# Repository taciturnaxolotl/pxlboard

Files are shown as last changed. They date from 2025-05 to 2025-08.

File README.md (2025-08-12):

# PxlBoard

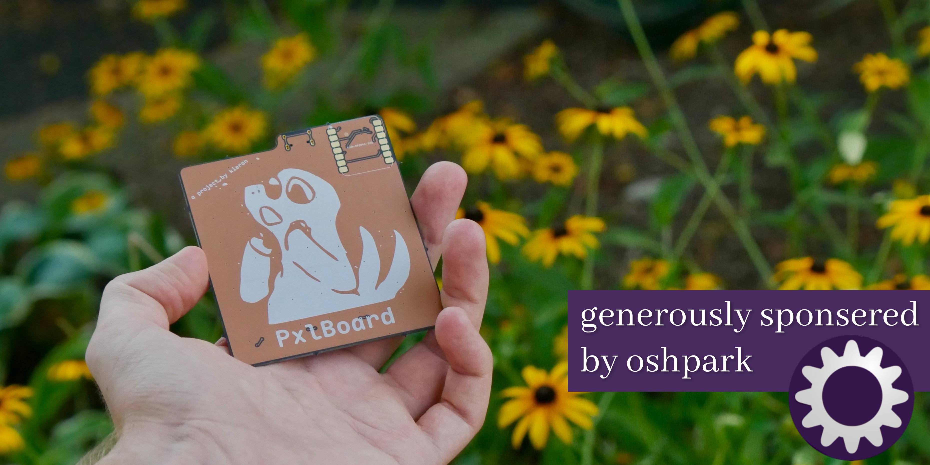
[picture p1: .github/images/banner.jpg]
the back of the pcb held in my hand over some black eyed susans


## BOM

| Part | Quantity | Price  | LCSC | Notes |
| --- | --- | --- | --- | --- |
| PCB (OSHPark) | 1 | $47.25 | | Purple PCB; Most expensive manufacturer but also looks gorgeous |
| PCB (JLCPCB) | 1 | $24.82 | | Custom PCB - Green; Mid-range price |
| PCB (PCBWay) | 1 | $12.80 | | Custom PCB - Various colors; Most affordable option (kinda suprisingly?) |
| Seeed XIAO RP2040 | 1 | $3.99  | [Seeed Studio](https://www.seeedstudio.com/XIAO-RP2040-v1-0-p-5026.html) | Brain of the operation |
| SK6812 LEDs | 65 | $6.40  | [C5380879](https://www.lcsc.com/product-detail/RGB-LEDs-Built-in-IC_OPSCO-Optoelectronics-SKC6812RGBW-WS-B_C5380879.html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) | RGB addressable LEDs; $0.0985 each, forms the 8x8 grid |
| LIS3DHTR Accelerometer | 1 | $0.60  | [C15134](https://www.lcsc.com/product-detail/Accelerometers_STMicroelectronics-LIS3DHTR_C15134.html?s_z=n_LIS3DHTR) | 3-axis accelerometer; same as the one used on the spark tilt jam |
| Capacitor 100nF - ceramic | 20 (min size) need 1 | $0.29  | [C24497](https://www.lcsc.com/product-detail/Multilayer-Ceramic-Capacitors-MLCC-SMD-SMT_Samsung-Electro-Mechanics-CL31B104KBCNNNC_C24497.html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) | 1206 package |
| Capacitor 10uF - ceramic | 10 (min size) need 9 | $0.34  | [C13585](https://www.lcsc.com/product-detail/Multilayer-Ceramic-Capacitors-MLCC-SMD-SMT_Samsung-Electro-Mechanics-CL31A106KBHNNNE_C13585.html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) | 1206 package |
| Capacitor 10nf - ceramic | 20 (min size) need 1 | $0.23  | [C1846](https://www.lcsc.com/product-detail/Multilayer-Ceramic-Capacitors-MLCC-SMD-SMT_FH-Guangdong-Fenghua-Advanced-Tech-1206B103K500NT_C1846.html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) | 1206 package |
| Capacitor 100uF - electrolytic | 5 (min size) need 1  | $0.87  | [C1954161](https://www.lcsc.com/product-detail/Tantalum-Capacitors_Vishay-Intertech-TMCMA0J107MTRF_C1954161.html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) | 1206 package |
| Capacitor 470uF - polymer | 5 (min size) need 1  | $0.59  | [C41410213](https://www.lcsc.com/product-detail/Polymer-Aluminum-Capacitors_Yunxing-SPT1AM471E09TRVZC_C41410213.html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) | 10V 470uF Polymer ±20% SMD,D6.3xL9mm Polymer Aluminum Capacitors ROHS |
| USB-c connector | 5 (min size) need 1  | $0.87  | [C165948](https://www.lcsc.com/product-detail/C165948.html) | 5A 1 16P Female Type-C SMD USB Connectors ROHS |

Total (with pcbway): ~$28.25

## Schematics

> If you want an iteractive version use [`kicanvas`](https://kicanvas.org/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)!

schematic

<div align="center">
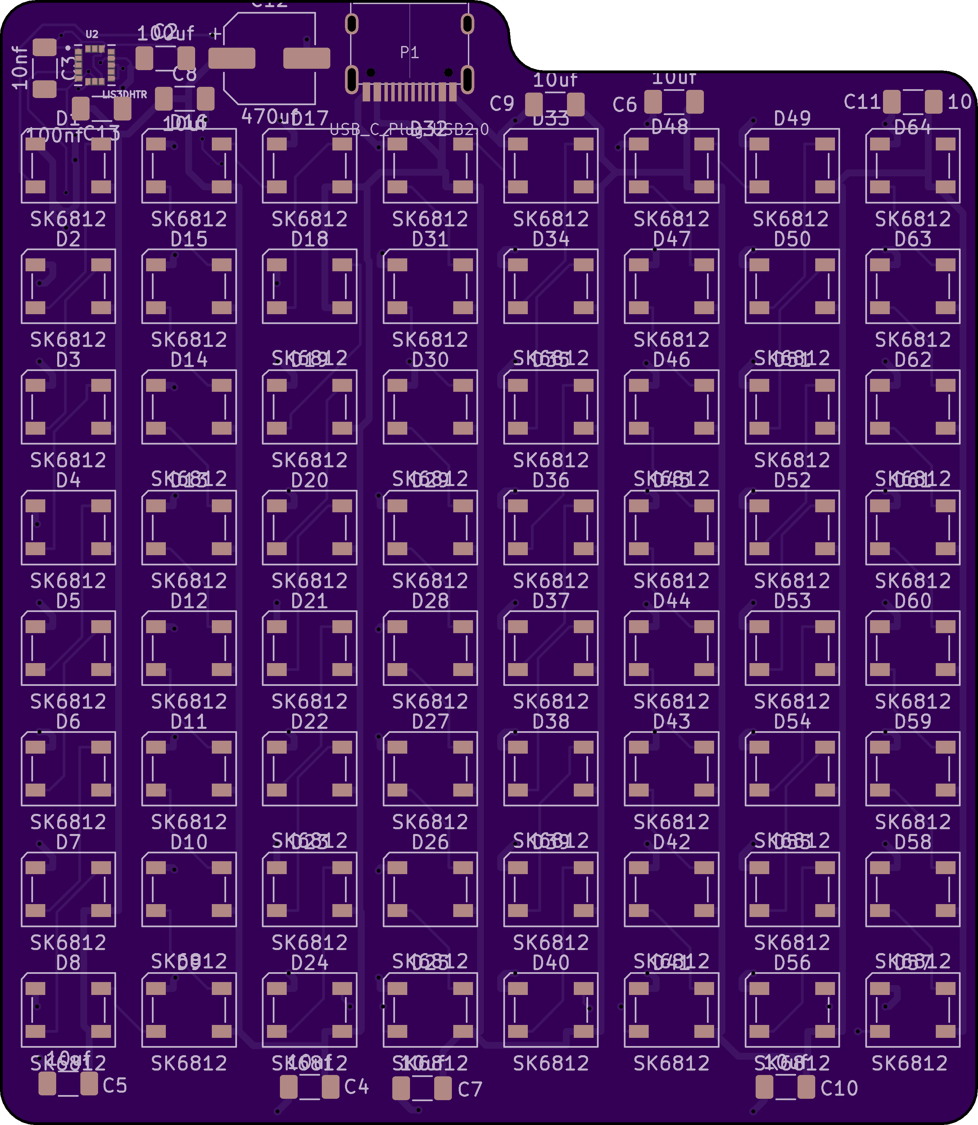
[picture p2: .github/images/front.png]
  
  
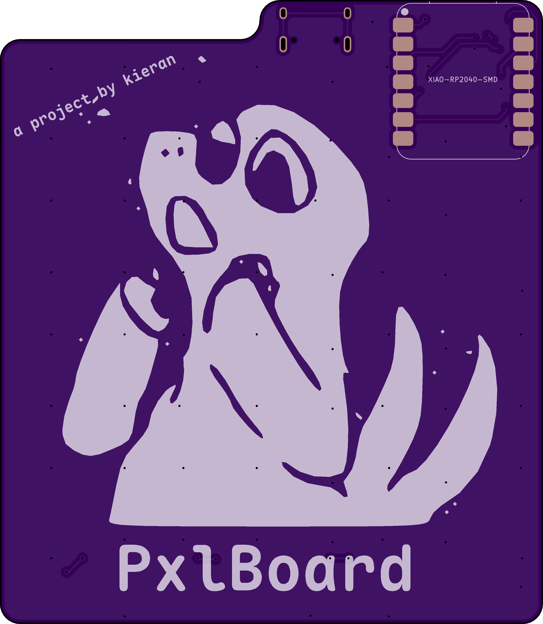
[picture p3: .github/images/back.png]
  
</div>

### Pinout

#### XIAO RP2040 Connections

| XIAO Pin | Connected To | Description |
| --- | --- | --- |
| D0/GPIO26/A0 | - | Unused |
| D1/GPIO27/A1 | - | Unused |
| D2/GPIO28/A2 | - | Unused |
| D3/GPIO29/A3 | - | Unused |
| D4/GPIO6/SDA | LIS3DHTR SDA | I2C Data Line  |
| D5/GPIO7/SCL | LIS3DHTR SCL | I2C Clock Line |
| D6/GPIO0/TX | - | Unused |
| D7/GPIO1/RX | NEOPIXEL_SIG | LED Data In |
| D8/GPIO2/SCK | - | Unused |
| D9/GPIO4/MISO  | - | Unused |
| D10/GPIO3/MOSI | - | Unused |
| 3V3 | LIS3DHTR VDD_IO | 3.3V Power |
| GND | LIS3DHTR GND, LEDs GND | Ground |
| 5V | LEDs VDD | 5V Power |

#### LIS3DHTR Accelerometer

| LIS3DHTR Pin | Connected To | Description |
| --- | --- | --- |
| VDD | 3.3V | Power Supply |
| VDD_IO | 3.3V | Interface Power |
| GND | GND | Ground |
| SDA | XIAO D4 | I2C Data |
| SCL | XIAO D5 | I2C Clock |
| INT1 | - | Interrupt (not used) |
| INT2 | - | Interrupt (not used) |

<p align="center">
	
</p>

<p align="center">
	<i><code>&copy 2025-present <a href="https://github.com/taciturnaxolotl">Kieran Klukas</a></code></i>
</p>

<p align="center">
	
</p>

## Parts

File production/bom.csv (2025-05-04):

Comment | Designator | Footprint | LCSC | Quantity
XIAO-RP2040-SMD | U1 | XIAO-RP2040-SMD | N/A | 1
SK6812 | D39,D31,D18,D37,D28,D21,D5,D3,D44,D24,D63,D52,D42,D56,D4,D43,D49,D60,D53,D62,D40,D50,D20,D41,D8,D30,D10,D58,D57,D33,D25,D16,D17,D23,D46,D59,D64,D27,D61,D7,D12,D19,D14,D36,D48,D54,D45,D55,D2,D29,D34,D35,D47,D1,D6,D26,D15,D38,D51,D9,D13,D22,D11,D32 | LED_SK6812_PLCC4_5.0x5.0mm_P3.2mm | C5380879 | 64
LIS3DHTR | U2 | XDCR_LIS3DHTR | C15134 | 1
100nF | C13 | C_1206_3216Metric_Pad1.33x1.80mm_HandSolder | C24497 | 1
10uF | C11,C4,C5,C10,C9,C8,C7,C6 | C_1206_3216Metric_Pad1.33x1.80mm_HandSolder | C13585 | 8
470uF | C12 | CP_Elec_6.3x9.9 | C41410213 | 1
100uF | C2 | C_1206_3216Metric_Pad1.33x1.80mm_HandSolder | C1954161 | 1
10nF | C3 | C_1206_3216Metric_Pad1.33x1.80mm_HandSolder | C1846 | 1

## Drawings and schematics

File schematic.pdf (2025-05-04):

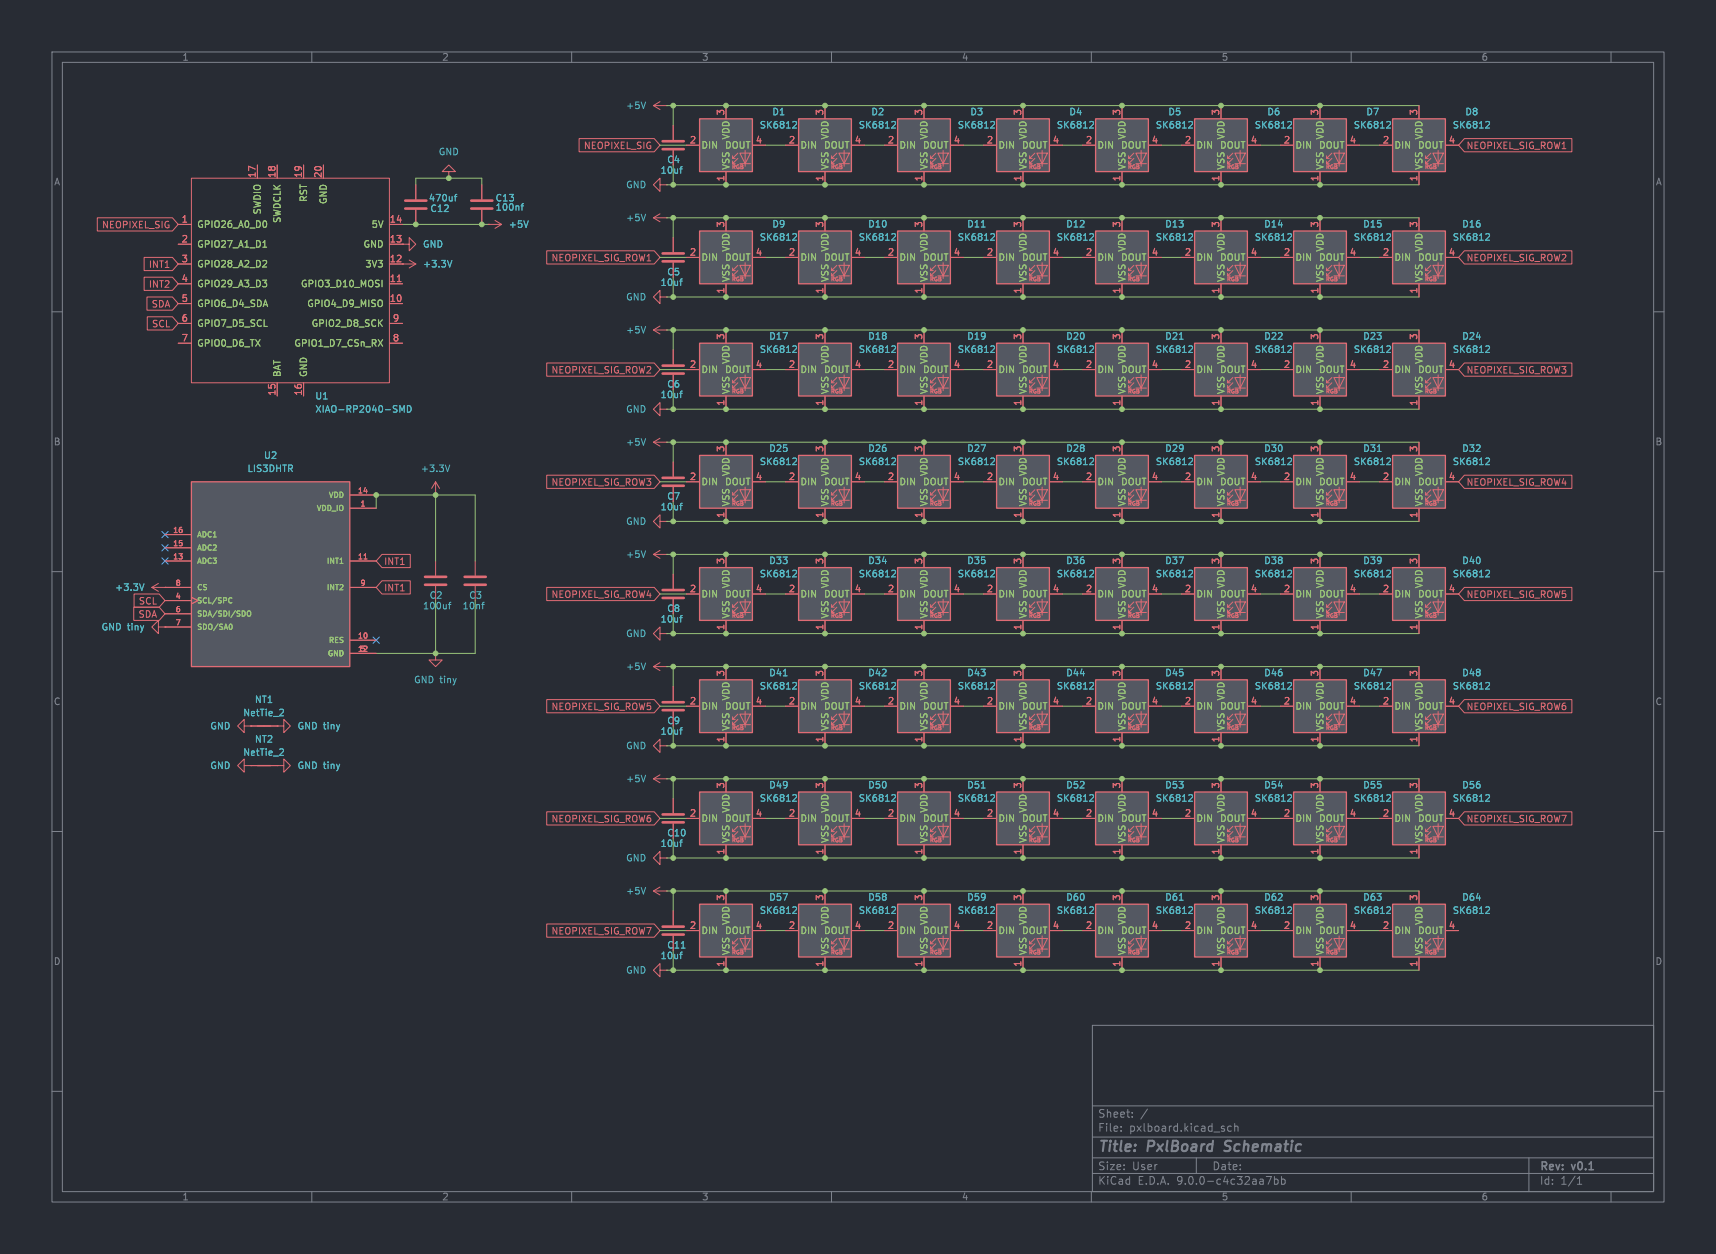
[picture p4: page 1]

1 DOUT 4 D32 SK6812 +3.3V GPIO26_A0_D0 1 GPIO27_A1_D1 2 GPIO28_A2_D2 3 GPIO29_A3_D3 4 GPIO6_D4_SDA 5 GPIO7_D5_SCL 6 GPIO0_D6_TX 7 SWDIO 17 SWDCLK 18 BAT 15 RST 19 GND 16 GND 20

1 DOUT 4 D39 SK6812 NT1 NetTie_2 GND GND tiny NT2 NetTie_2

File: pxlboard.kicad_sch Sheet: /
Id: 1/1 Title: PxlBoard Schematic

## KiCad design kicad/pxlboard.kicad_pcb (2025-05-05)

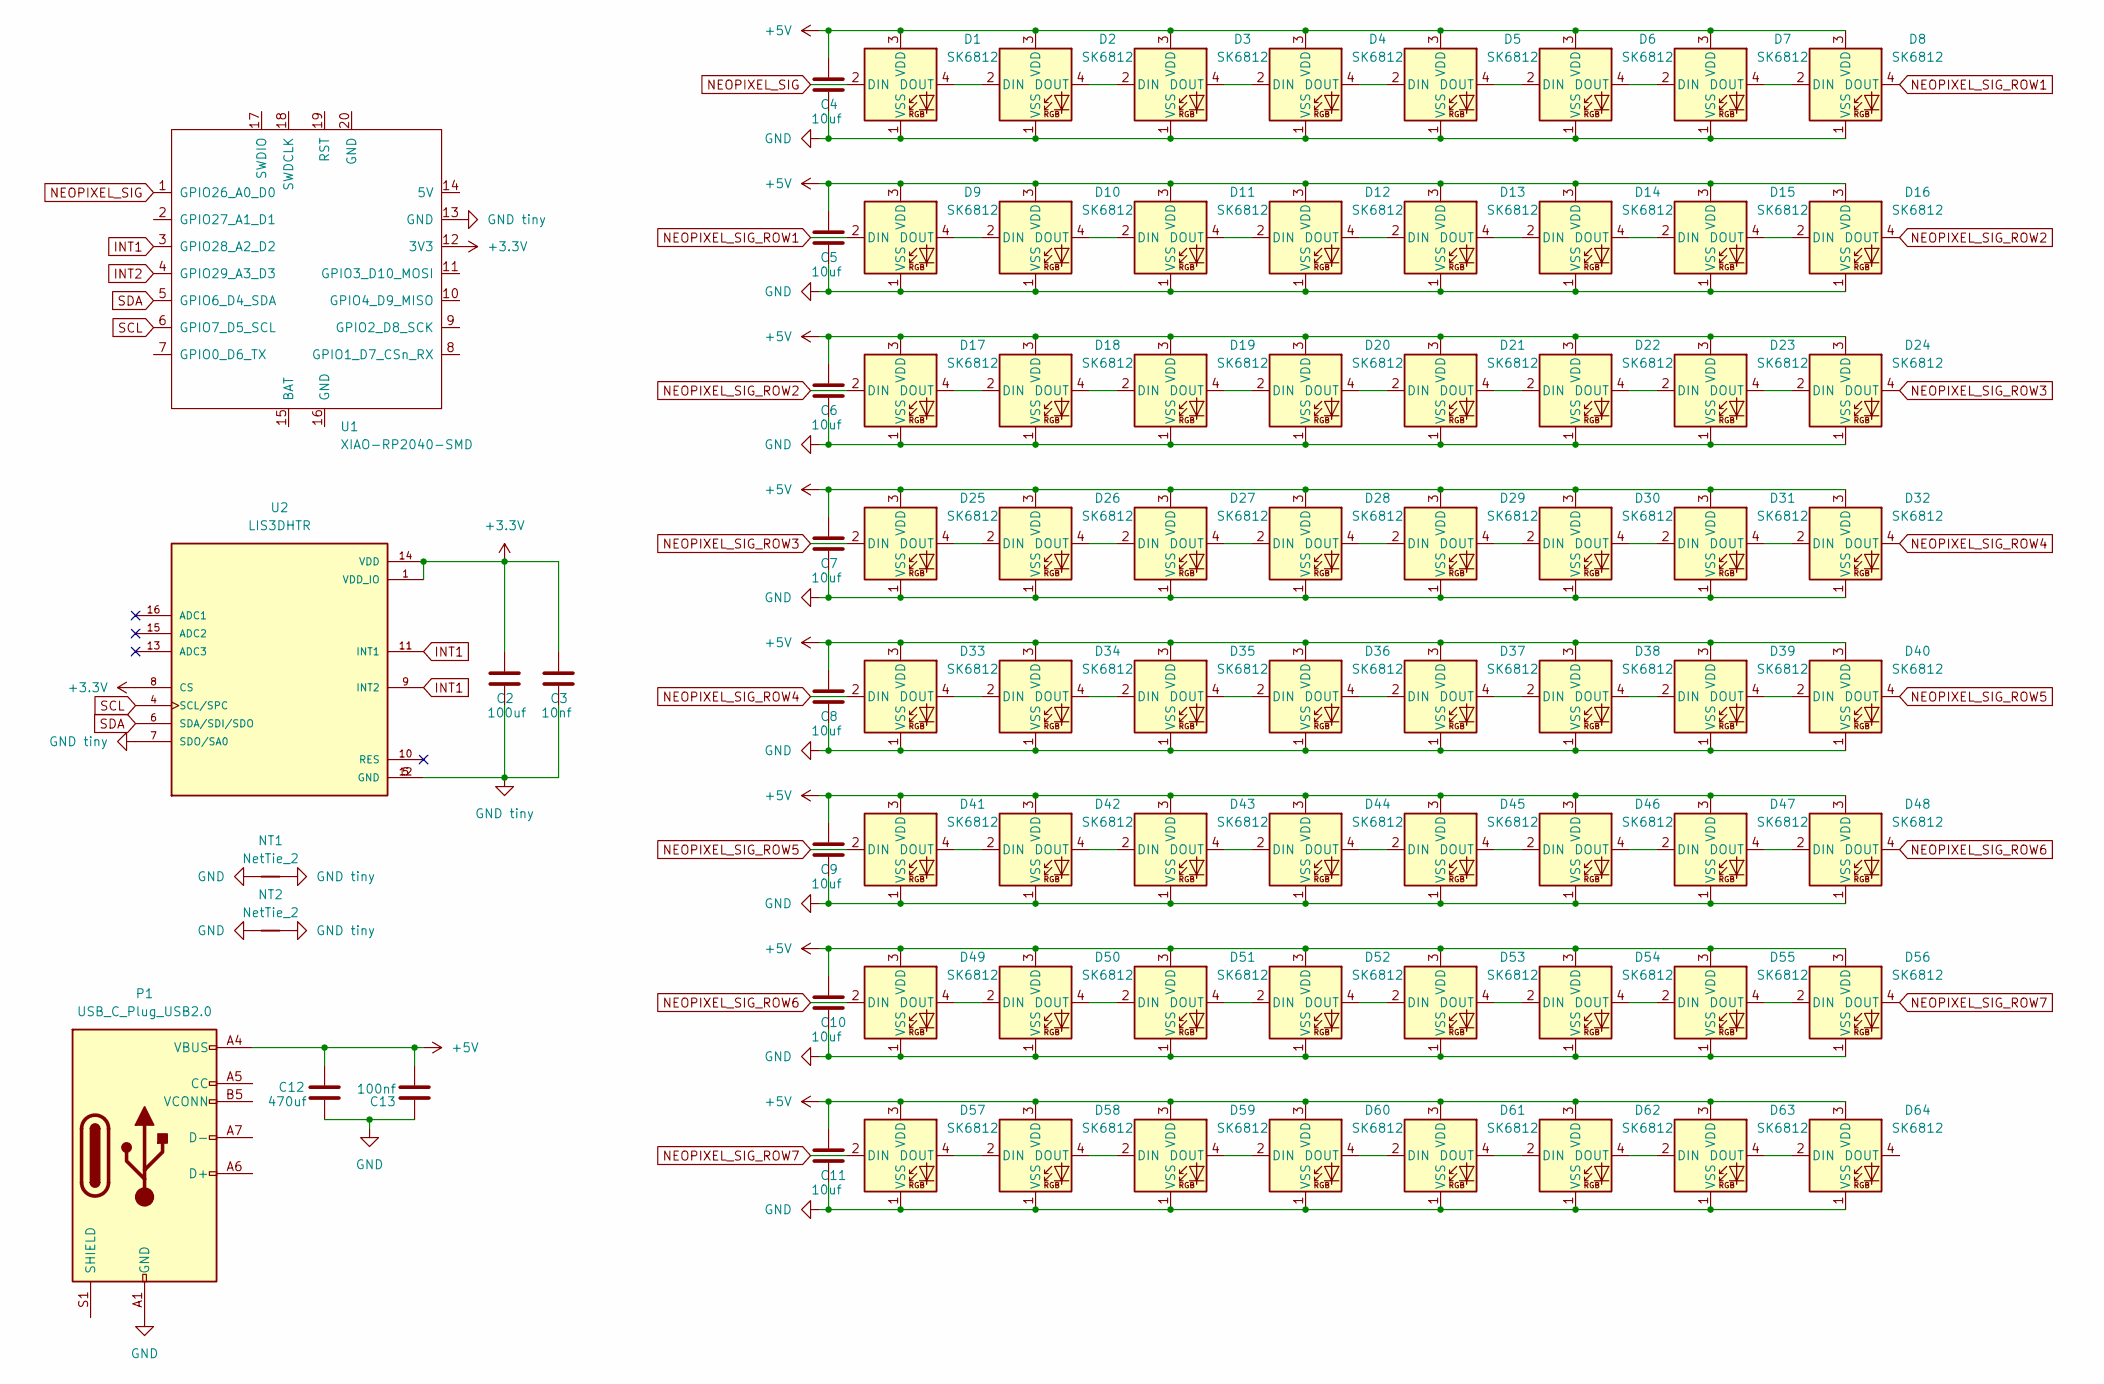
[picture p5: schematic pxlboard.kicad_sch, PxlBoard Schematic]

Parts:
C2: 100uf; C_1206_3216Metric_Pad1.33x1.80mm_HandSolder
C3: 10nf; C_1206_3216Metric_Pad1.33x1.80mm_HandSolder
C4, C5, C6, C7, C8, C9, C10, C11: 10uf; C_1206_3216Metric_Pad1.33x1.80mm_HandSolder
C12: 470uf; CP_Elec_6.3x9.9
C13: 100nf; C_1206_3216Metric_Pad1.33x1.80mm_HandSolder
D1, D2, D3, D4, D5, D6, D7, D8, D9, D10, D11, D12, D13, D14, D15, D16, D17, D18, D19, D20, D21, D22, D23, D24, D25, D26, D27, D28, D29, D30, D31, D32, D33, D34, D35, D36, D37, D38, D39, D40, D41, D42, D43, D44, D45, D46, D47, D48, D49, D50, D51, D52, D53, D54, D55, D56, D57, D58, D59, D60, D61, D62, D63, D64: SK6812; LED_SK6812_PLCC4_5.0x5.0mm_P3.2mm
NT1, NT2: NetTie_2; NetTie-2_SMD_Pad0.5mm
P1: USB_C_Plug_USB2.0; TYPE-C-31-M-12
U1: XIAO-RP2040-SMD
U2: LIS3DHTR; XDCR_LIS3DHTR; PARTREV 2; DigiKey_Part_Number 497-10613-2-ND

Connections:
+3.3V: C2.1, C3.1, U1.12 (3V3), U2.1 (VDD_IO), U2.8 (CS), U2.14 (VDD)
+5V: C4.1, C5.1, C6.1, C7.1, C8.1, C9.1, C10.1, C11.1, C12.1, C13.2, D1.3 (VDD), D2.3 (VDD), D3.3 (VDD), D4.3 (VDD), D5.3 (VDD), D6.3 (VDD), D7.3 (VDD), D8.3 (VDD), D9.3 (VDD), D10.3 (VDD), D11.3 (VDD), D12.3 (VDD), D13.3 (VDD), D14.3 (VDD), D15.3 (VDD), D16.3 (VDD), D17.3 (VDD), D18.3 (VDD), D19.3 (VDD), D20.3 (VDD), D21.3 (VDD), D22.3 (VDD), D23.3 (VDD), D24.3 (VDD), D25.3 (VDD), D26.3 (VDD), D27.3 (VDD), D28.3 (VDD), D29.3 (VDD), D30.3 (VDD), D31.3 (VDD), D32.3 (VDD), D33.3 (VDD), D34.3 (VDD), D35.3 (VDD), D36.3 (VDD), D37.3 (VDD), D38.3 (VDD), D39.3 (VDD), D40.3 (VDD), D41.3 (VDD), D42.3 (VDD), D43.3 (VDD), D44.3 (VDD), D45.3 (VDD), D46.3 (VDD), D47.3 (VDD), D48.3 (VDD), D49.3 (VDD), D50.3 (VDD), D51.3 (VDD), D52.3 (VDD), D53.3 (VDD), D54.3 (VDD), D55.3 (VDD), D56.3 (VDD), D57.3 (VDD), D58.3 (VDD), D59.3 (VDD), D60.3 (VDD), D61.3 (VDD), D62.3 (VDD), D63.3 (VDD), D64.3 (VDD), P1.A4 (VBUS), P1.A9 (VBUS), P1.B4 (VBUS), P1.B9 (VBUS)
GND: C4.2, C5.2, C6.2, C7.2, C8.2, C9.2, C10.2, C11.2, C12.2, C13.1, D1.1 (VSS), D2.1 (VSS), D3.1 (VSS), D4.1 (VSS), D5.1 (VSS), D6.1 (VSS), D7.1 (VSS), D8.1 (VSS), D9.1 (VSS), D10.1 (VSS), D11.1 (VSS), D12.1 (VSS), D13.1 (VSS), D14.1 (VSS), D15.1 (VSS), D16.1 (VSS), D17.1 (VSS), D18.1 (VSS), D19.1 (VSS), D20.1 (VSS), D21.1 (VSS), D22.1 (VSS), D23.1 (VSS), D24.1 (VSS), D25.1 (VSS), D26.1 (VSS), D27.1 (VSS), D28.1 (VSS), D29.1 (VSS), D30.1 (VSS), D31.1 (VSS), D32.1 (VSS), D33.1 (VSS), D34.1 (VSS), D35.1 (VSS), D36.1 (VSS), D37.1 (VSS), D38.1 (VSS), D39.1 (VSS), D40.1 (VSS), D41.1 (VSS), D42.1 (VSS), D43.1 (VSS), D44.1 (VSS), D45.1 (VSS), D46.1 (VSS), D47.1 (VSS), D48.1 (VSS), D49.1 (VSS), D50.1 (VSS), D51.1 (VSS), D52.1 (VSS), D53.1 (VSS), D54.1 (VSS), D55.1 (VSS), D56.1 (VSS), D57.1 (VSS), D58.1 (VSS), D59.1 (VSS), D60.1 (VSS), D61.1 (VSS), D62.1 (VSS), D63.1 (VSS), D64.1 (VSS), NT1.1, NT2.1, P1.A1 (GND), P1.A12 (GND), P1.B1 (GND), P1.B12 (GND)
GND tiny: C2.2, C3.2, NT1.2, NT2.2, U1.13 (GND), U2.5 (GND), U2.7 (SDO/SA0), U2.12 (GND)
INT1: U1.3 (GPIO28_A2_D2), U2.9 (INT2), U2.11 (INT1)
INT2: U1.4 (GPIO29_A3_D3)
NEOPIXEL_SIG: D1.2 (DIN), U1.1 (GPIO26_A0_D0)
NEOPIXEL_SIG_ROW1: D8.4 (DOUT), D9.2 (DIN)
NEOPIXEL_SIG_ROW2: D16.4 (DOUT), D17.2 (DIN)
NEOPIXEL_SIG_ROW3: D24.4 (DOUT), D25.2 (DIN)
NEOPIXEL_SIG_ROW4: D32.4 (DOUT), D33.2 (DIN)
NEOPIXEL_SIG_ROW5: D40.4 (DOUT), D41.2 (DIN)
NEOPIXEL_SIG_ROW6: D48.4 (DOUT), D49.2 (DIN)
NEOPIXEL_SIG_ROW7: D56.4 (DOUT), D57.2 (DIN)
unnamed: D1.4 (DOUT), D2.2 (DIN)
unnamed: D2.4 (DOUT), D3.2 (DIN)
unnamed: D3.4 (DOUT), D4.2 (DIN)
unnamed: D4.4 (DOUT), D5.2 (DIN)
unnamed: D5.4 (DOUT), D6.2 (DIN)
unnamed: D6.4 (DOUT), D7.2 (DIN)
unnamed: D7.4 (DOUT), D8.2 (DIN)
unnamed: D9.4 (DOUT), D10.2 (DIN)
unnamed: D10.4 (DOUT), D11.2 (DIN)
unnamed: D11.4 (DOUT), D12.2 (DIN)
unnamed: D12.4 (DOUT), D13.2 (DIN)
unnamed: D13.4 (DOUT), D14.2 (DIN)
unnamed: D14.4 (DOUT), D15.2 (DIN)
unnamed: D15.4 (DOUT), D16.2 (DIN)
unnamed: D17.4 (DOUT), D18.2 (DIN)
unnamed: D18.4 (DOUT), D19.2 (DIN)
unnamed: D19.4 (DOUT), D20.2 (DIN)
unnamed: D20.4 (DOUT), D21.2 (DIN)
unnamed: D21.4 (DOUT), D22.2 (DIN)
unnamed: D22.4 (DOUT), D23.2 (DIN)
unnamed: D23.4 (DOUT), D24.2 (DIN)
unnamed: D25.4 (DOUT), D26.2 (DIN)
unnamed: D26.4 (DOUT), D27.2 (DIN)
unnamed: D27.4 (DOUT), D28.2 (DIN)
unnamed: D28.4 (DOUT), D29.2 (DIN)
unnamed: D29.4 (DOUT), D30.2 (DIN)
unnamed: D30.4 (DOUT), D31.2 (DIN)
unnamed: D31.4 (DOUT), D32.2 (DIN)
unnamed: D33.4 (DOUT), D34.2 (DIN)
unnamed: D34.4 (DOUT), D35.2 (DIN)
unnamed: D35.4 (DOUT), D36.2 (DIN)
unnamed: D36.4 (DOUT), D37.2 (DIN)
unnamed: D37.4 (DOUT), D38.2 (DIN)
unnamed: D38.4 (DOUT), D39.2 (DIN)
unnamed: D39.4 (DOUT), D40.2 (DIN)
unnamed: D41.4 (DOUT), D42.2 (DIN)
unnamed: D42.4 (DOUT), D43.2 (DIN)
unnamed: D43.4 (DOUT), D44.2 (DIN)
unnamed: D44.4 (DOUT), D45.2 (DIN)
unnamed: D45.4 (DOUT), D46.2 (DIN)
unnamed: D46.4 (DOUT), D47.2 (DIN)
unnamed: D47.4 (DOUT), D48.2 (DIN)
unnamed: D49.4 (DOUT), D50.2 (DIN)
unnamed: D50.4 (DOUT), D51.2 (DIN)
unnamed: D51.4 (DOUT), D52.2 (DIN)
unnamed: D52.4 (DOUT), D53.2 (DIN)
unnamed: D53.4 (DOUT), D54.2 (DIN)
unnamed: D54.4 (DOUT), D55.2 (DIN)
unnamed: D55.4 (DOUT), D56.2 (DIN)
unnamed: D57.4 (DOUT), D58.2 (DIN)
unnamed: D58.4 (DOUT), D59.2 (DIN)
unnamed: D59.4 (DOUT), D60.2 (DIN)
unnamed: D60.4 (DOUT), D61.2 (DIN)
unnamed: D61.4 (DOUT), D62.2 (DIN)
unnamed: D62.4 (DOUT), D63.2 (DIN)
unnamed: D63.4 (DOUT), D64.2 (DIN)
SCL: U1.6 (GPIO7_D5_SCL), U2.4 (SCL/SPC)
SDA: U1.5 (GPIO6_D4_SDA), U2.6 (SDA/SDI/SDO)

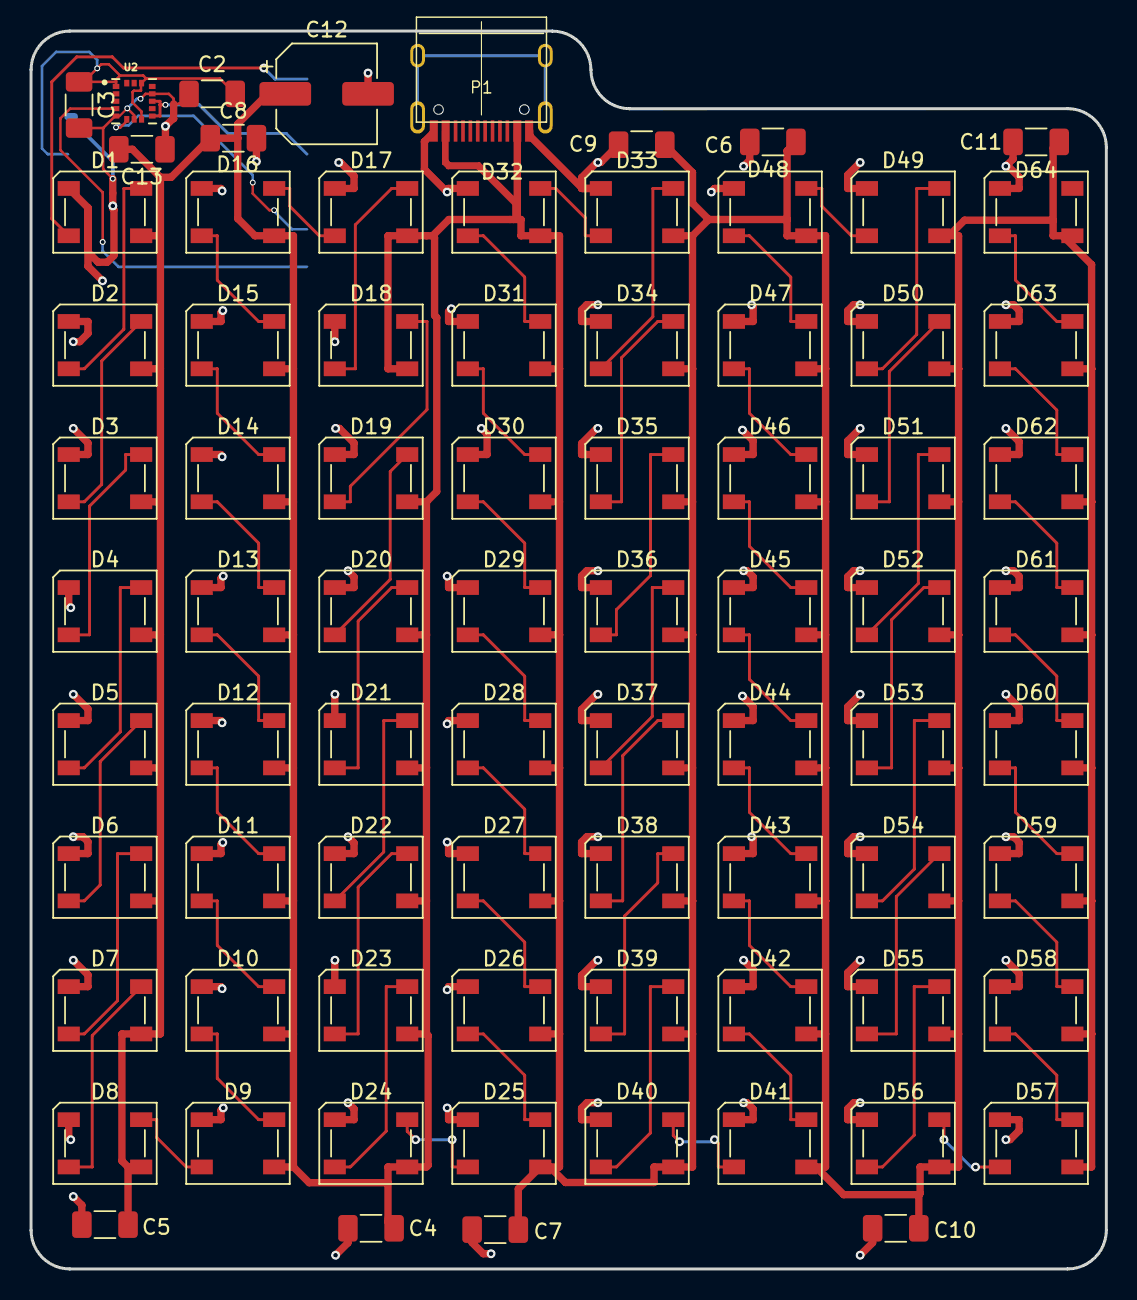
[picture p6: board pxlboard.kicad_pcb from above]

Board: 2 copper layers, 72.8 x 83.8 mm, 81 parts (1 on the bottom side), 71 nets.

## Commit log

2025-05-03 feat: add kicad and schematic
    [pxlboard.kicad_pcb, pxlboard.kicad_sch]
2025-05-03 feat: add basic matrix
    [pxlboard.kicad_pcb]
2025-05-03 feat: add accelerometer
    [pxlboard.kicad_pcb, pxlboard.kicad_sch]
2025-05-03 feat: 64 leds and proper trace width
    [pxlboard.kicad_pcb, pxlboard.kicad_sch]
2025-05-03 feat: round off the board
    [pxlboard.kicad_pcb]
2025-05-03 feat: export for production
    [pxlboard.kicad_pcb]
2025-05-03 feat: add bom
2025-05-03 docs: add wiring
2025-05-04 docs: update bom
2025-05-04 feat: add caps and reroute
    [pxlboard.kicad_pcb, pxlboard.kicad_sch]
2025-05-04 docs: add schematic and pcb
    [pxlboard.kicad_pcb]
2025-05-04 feat: add production
    [bom.csv]
2025-05-05 feat: round corners
    [pxlboard.kicad_pcb]
2025-05-05 feat: add power usb c
    [pxlboard.kicad_pcb, pxlboard.kicad_sch]
2025-08-11 docs: add type c connector to bom
